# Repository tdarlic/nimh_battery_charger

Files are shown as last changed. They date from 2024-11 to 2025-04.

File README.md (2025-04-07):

# NiMh Battery Charger for 4 AA/AAA batteries

Idea taken from BigClive:
[https://www.reddit.com/r/BigCliveDotCom/comments/tcny85/simple_nimh_battery_charger_with_pcb_files/]

In order to know when the batteries might be charged my plan was to use the timer and a LED. 
I need a 24 hour timer and 555 adds more complications and cannot have 24 hours delays.
Then I tried to get a more modern timer solution but at the end it's much cheaper to use cheap MCU.
That seems wastefull to use MCU only as a timer so I'll ad some fluff to it and maybe connect more batteries to one.

For detecting battery and the timers used ch32v003fun:
[https://github.com/cnlohr/ch32v003fun?tab=readme-ov-file]

Example of the dev board:
[https://oshwlab.com/wagiminator/ch32v003f4p6-development-board]

Development board github:
[https://github.com/wuxx/nanoCH32V003]

To use the WCH-LinkE on Linux, you need to grant access permissions beforehand by executing the following commands:

```shell
echo 'SUBSYSTEM=="usb", ATTR{idVendor}=="1a86", ATTR{idProduct}=="8010", MODE="666"' | sudo tee /etc/udev/rules.d/99-WCH-LinkE.rules
echo 'SUBSYSTEM=="usb", ATTR{idVendor}=="1a86", ATTR{idProduct}=="8012", MODE="666"' | sudo tee -a /etc/udev/rules.d/99-WCH-LinkE.rules
sudo udevadm control --reload-rules

```

To upload firmware and perform debugging, you need to ensure that the development board is disconnected from any power sources. Then, you should make the following connections to the WCH-LinkE:
```
| WCH-LinkE |      | DevBoard |
|-----------|------|----------|
|  SWDIO    | <--> |DIO       |
|    3V3    | ---> |3V3       |
|    GND    | ---> |GND       |

```
## NRST [D7] pin AS GPIO
Must be configured to be GPIO and not NRST pin
```shell
./minichlink -D
```
New make command was added to do this
```shell
make nrstoff
```

## Quick reference
ch32v003f4u6

## Dev board pinout
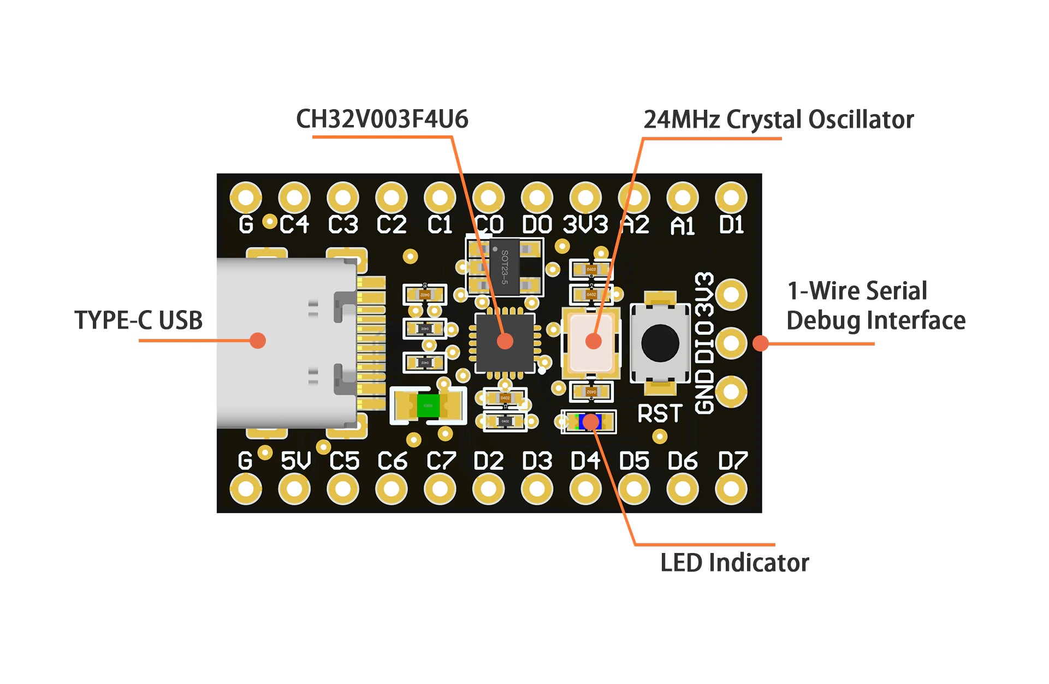
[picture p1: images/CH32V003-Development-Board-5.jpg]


## Dev board schematic 
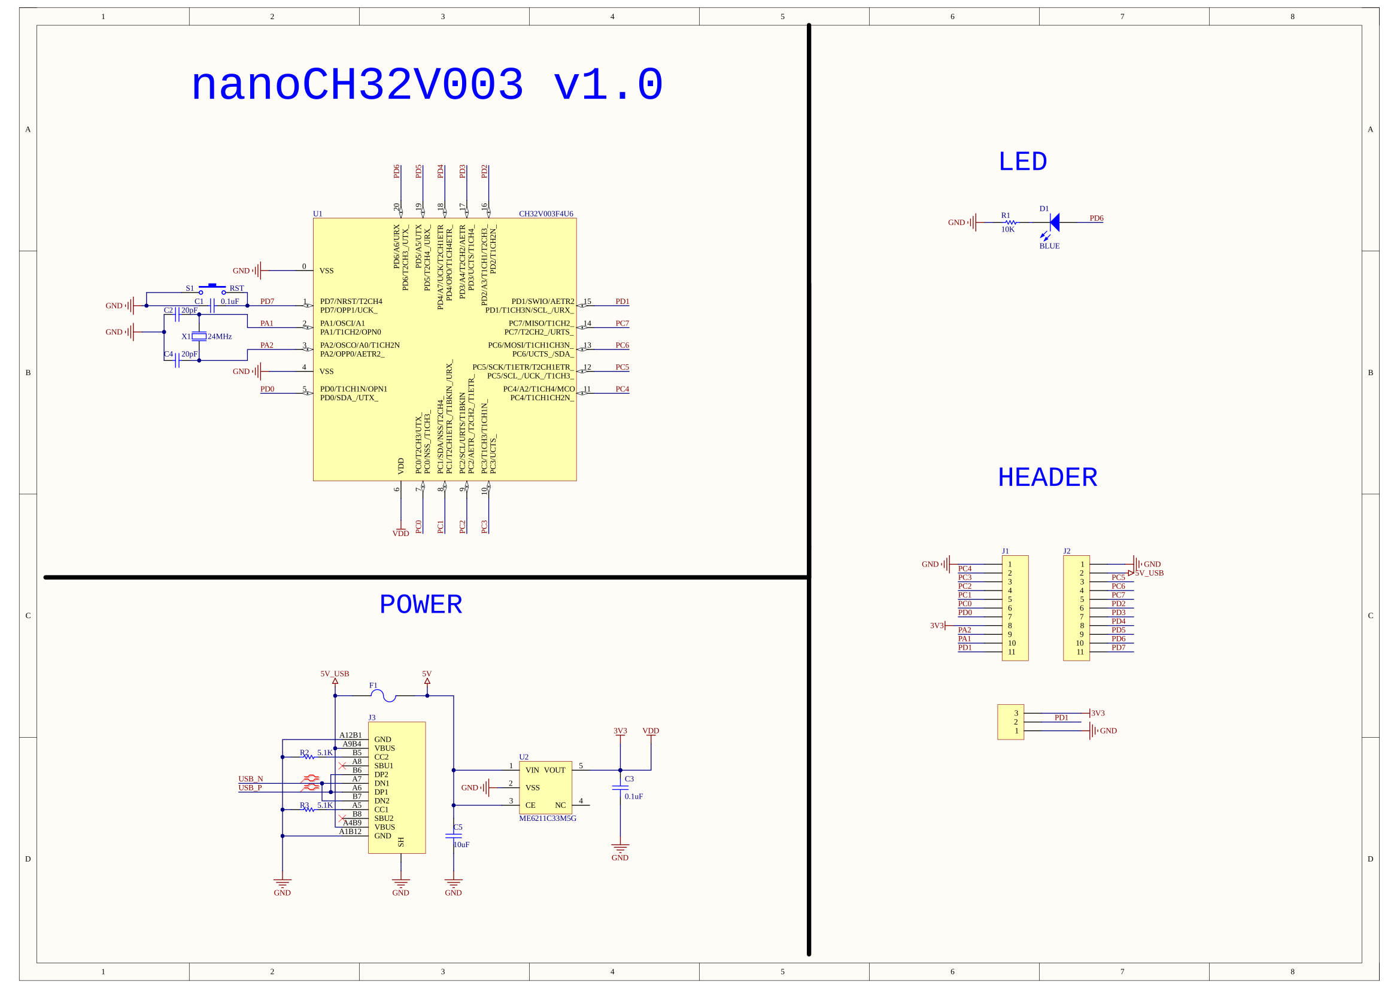
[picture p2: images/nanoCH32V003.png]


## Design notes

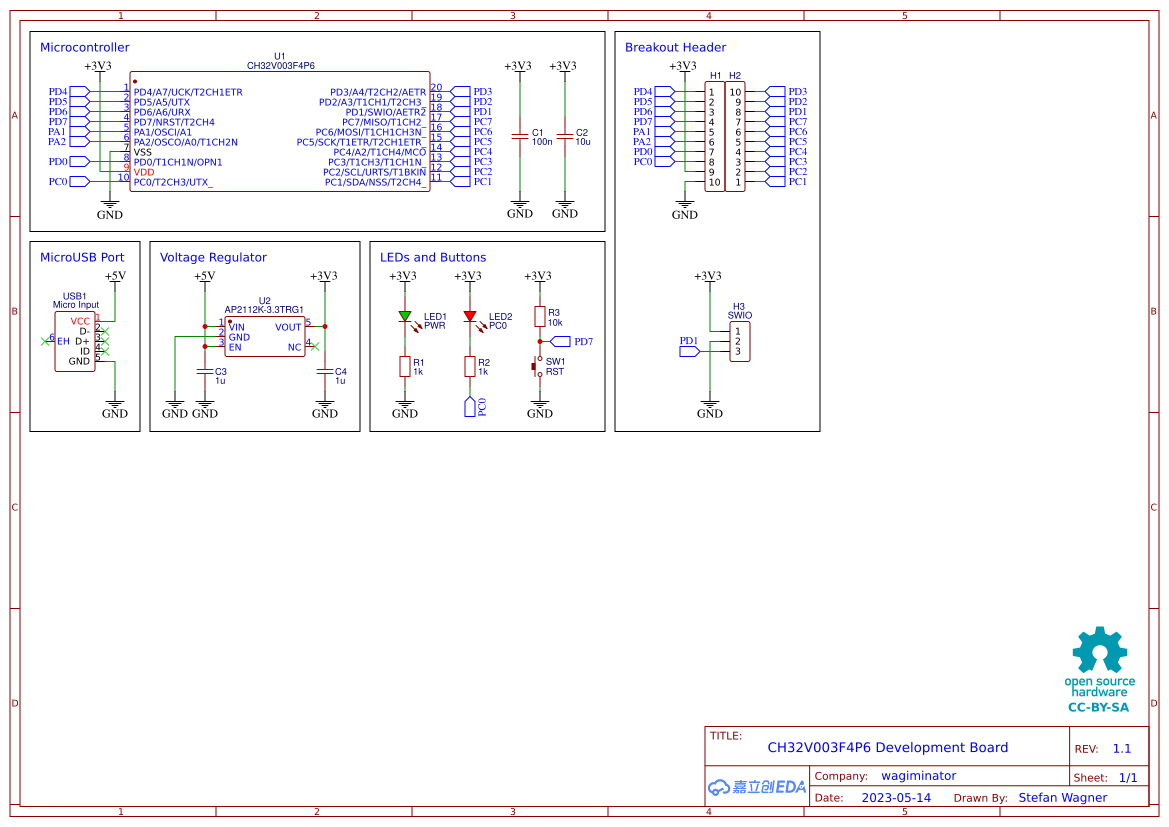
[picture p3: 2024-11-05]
images/36106731c64941528ee92b157d8d4ac0.png

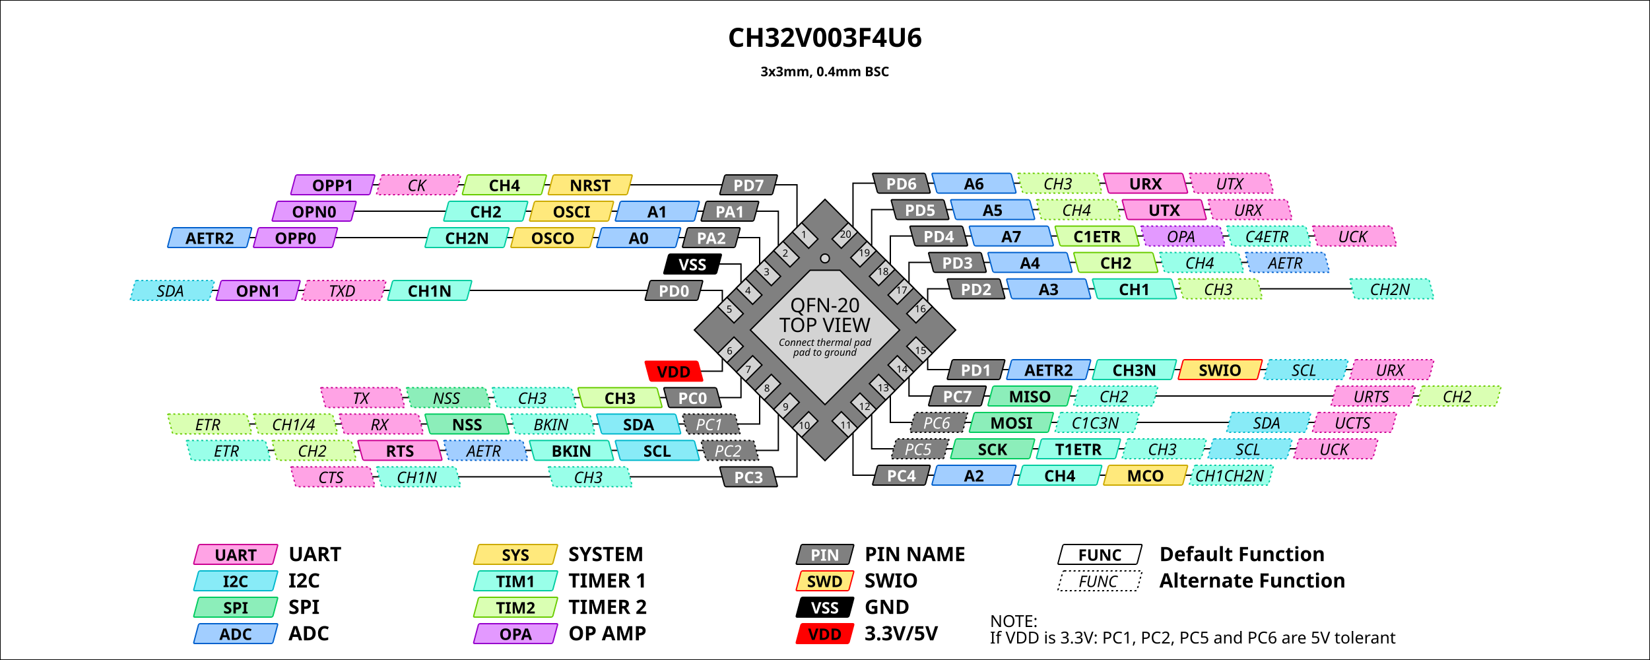
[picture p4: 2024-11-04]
images/ch32v003f4u6.png

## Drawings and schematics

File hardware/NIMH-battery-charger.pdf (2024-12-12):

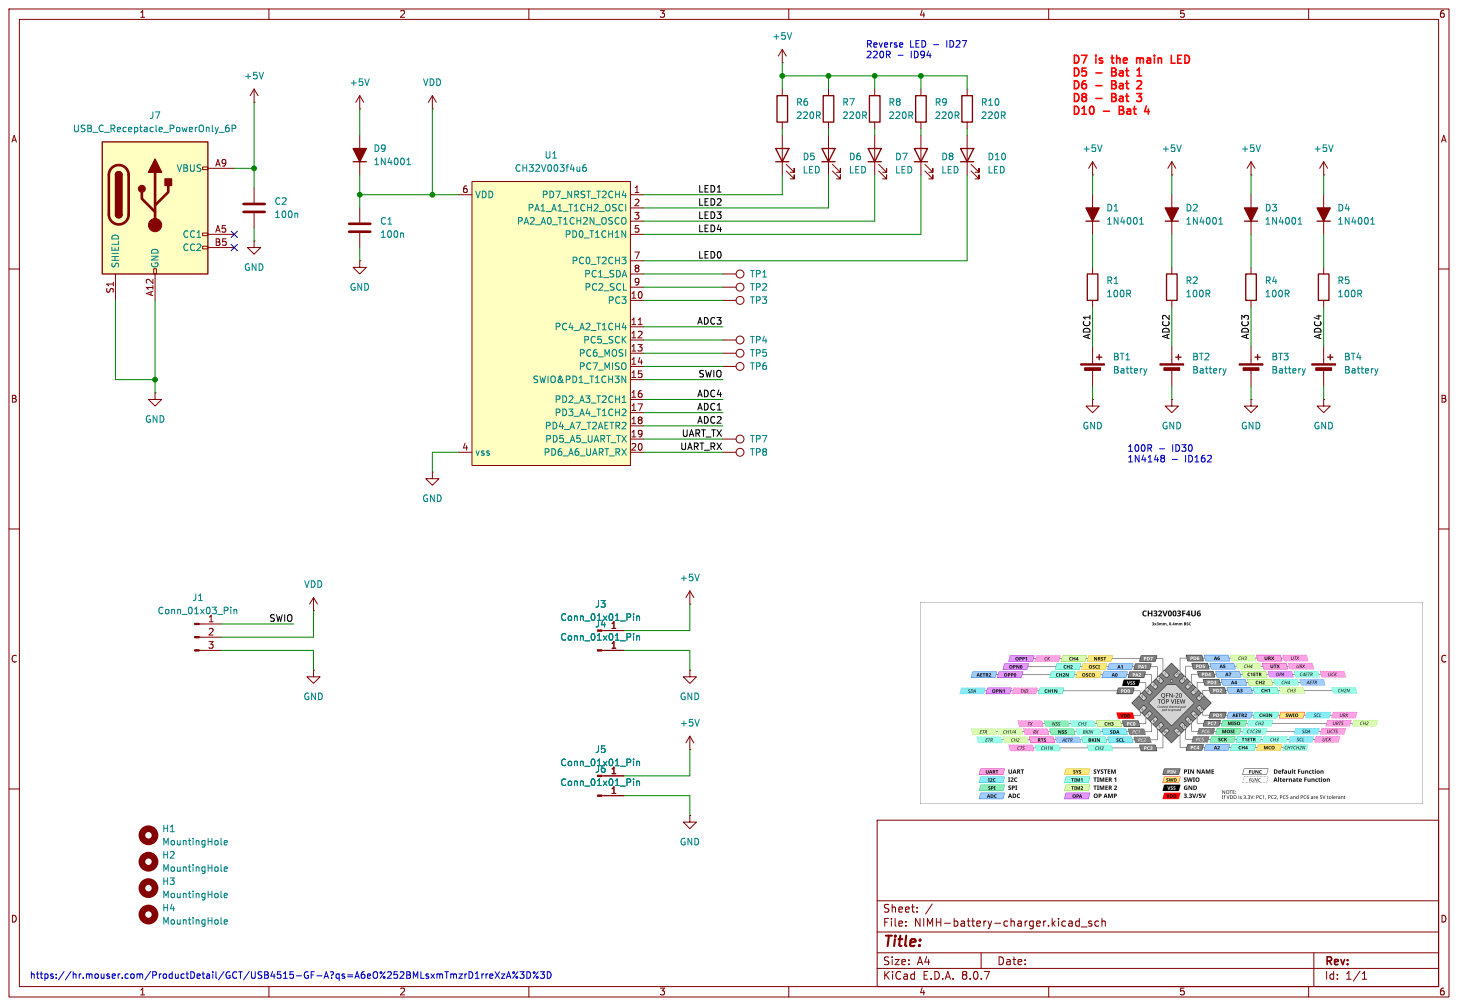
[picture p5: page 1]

D5 - Bat 1 D6 - Bat 2 D8 - Bat 3 D10 - Bat 4

Id: 1/1 Title: File: NIMH-battery-charger.kicad_sch Sheet: / 1

https://hr.mouser.com/ProductDetail/GCT/USB4515-GF-A?qs=A6eO%252BMLsxmTmzrD1rreXzA%3D%3D

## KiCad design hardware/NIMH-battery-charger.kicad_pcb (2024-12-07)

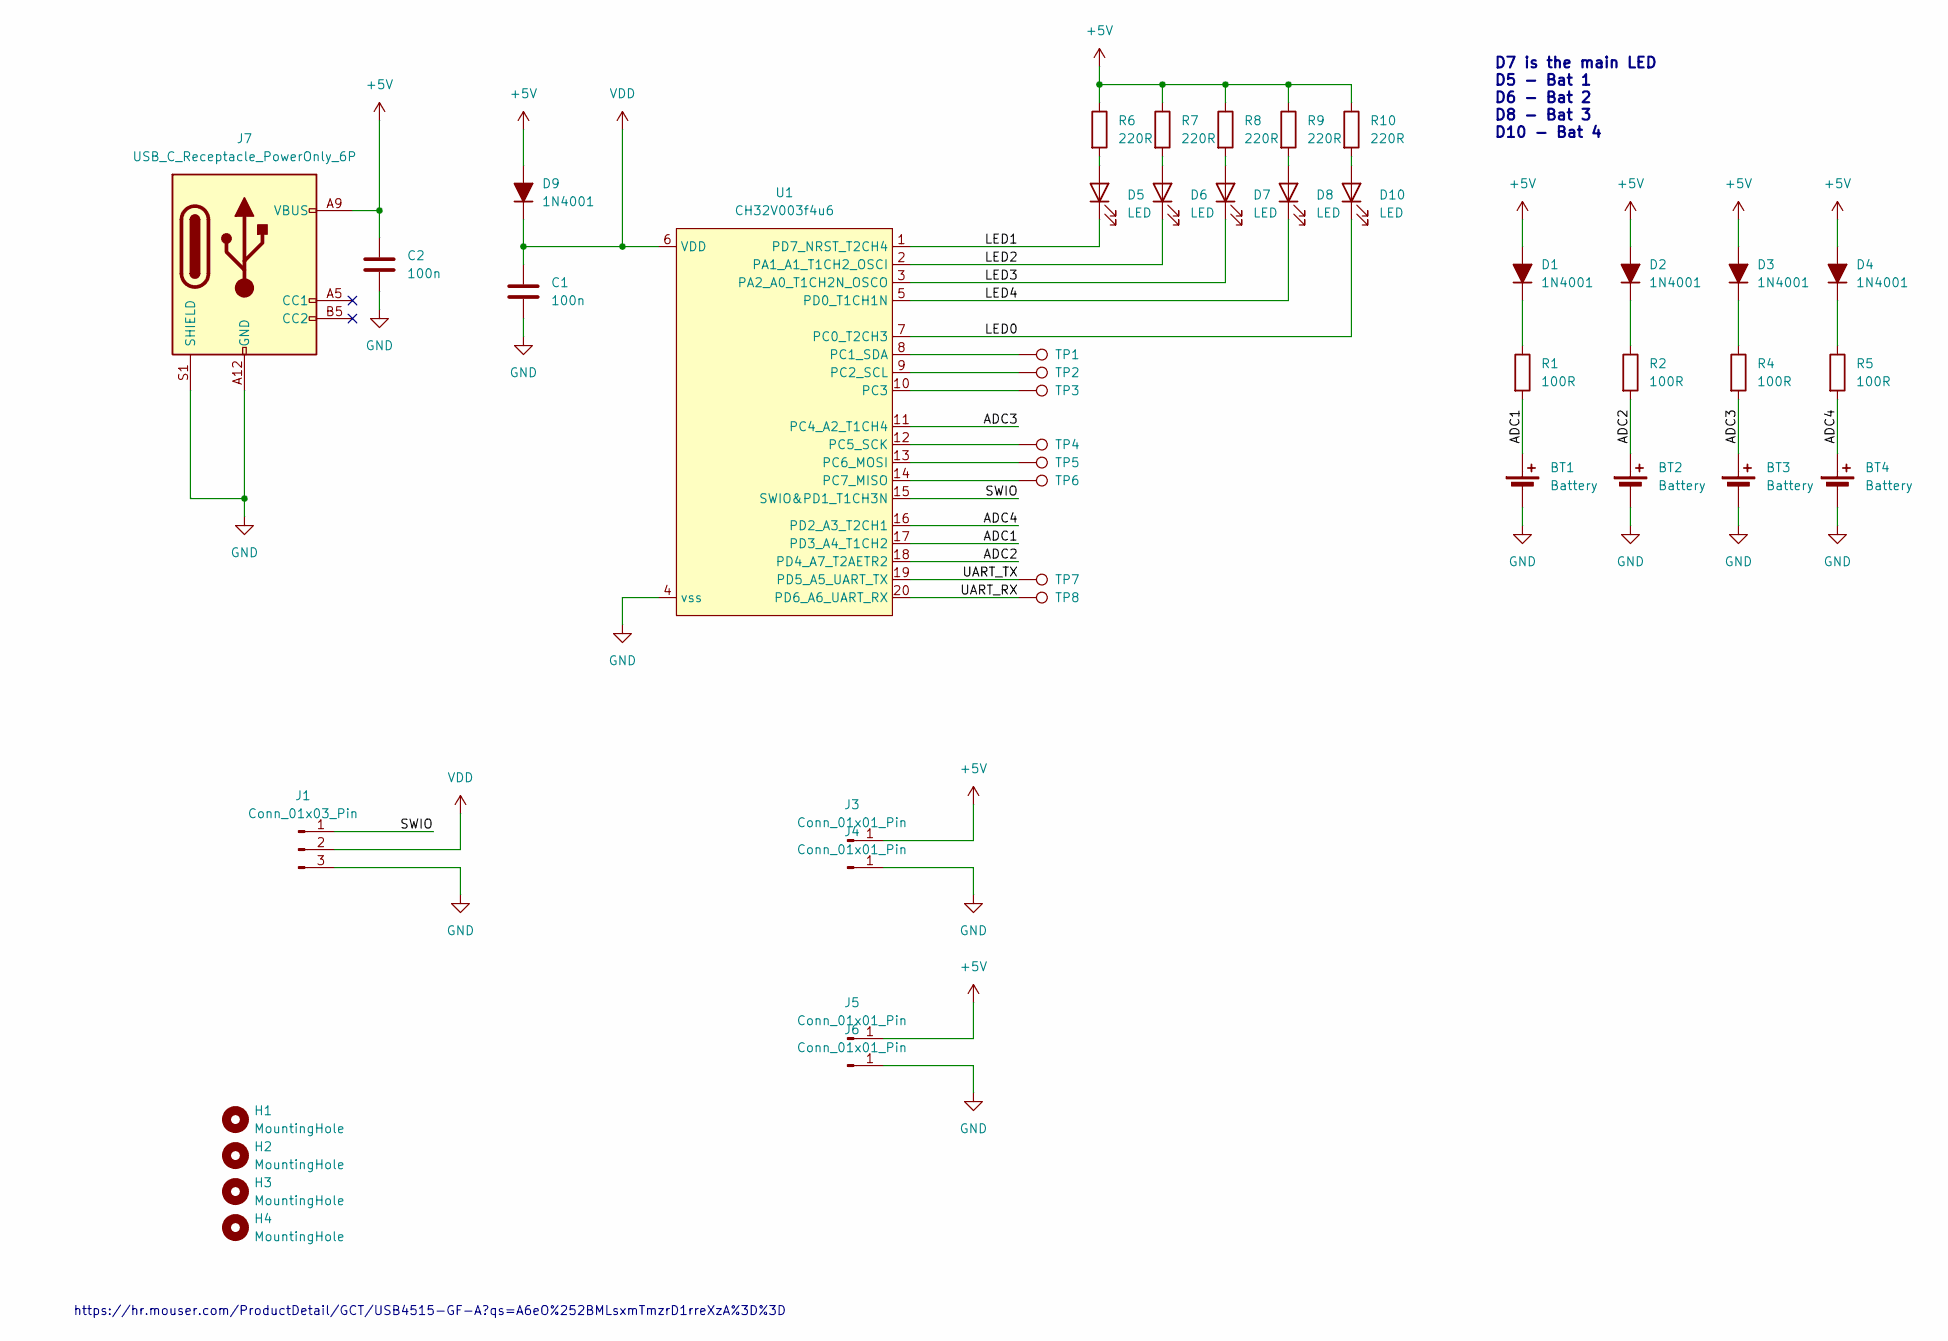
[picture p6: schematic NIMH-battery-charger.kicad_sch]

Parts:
BT1, BT2, BT3, BT4: Battery; UM-3X1-AA
C1, C2: 100n; C_0805_2012Metric_Pad1.18x1.45mm
D1, D2, D3, D4, D9: 1N4001; D_SOD-323_BigPads
D5, D6, D7, D8, D10: LED; LED_1206_3216Metric_ReverseMount_Hole1.8x2.4mm
H1, H2, H3, H4: MountingHole; MountingHole_3.2mm_M3_ISO14580_Pad_TopOnly
J1: Conn_01x03_Pin; Harwin_M20-89003xx_1x03_P2.54mm_Horizontal
J3, J4, J5, J6: Conn_01x01_Pin; PAD
J7: USB_C_Receptacle_PowerOnly_6P; USB4515-GF-A
R1, R2, R4, R5: 100R; R_0805_2012Metric_Pad1.20x1.40mm_HandSolder
R6, R7, R8, R9, R10: 220R; R_0805_2012Metric_Pad1.20x1.40mm_HandSolder
TP1, TP2, TP3, TP4, TP5, TP6, TP7, TP8: TestPoint; TestPoint_Pad_D1.5mm
U1: CH32V003f4u6; QFN-20-1EP_3x3mm_P0.4mm_EP1.65x1.65mm

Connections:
+5V: C2.1, D1.2 (A), D2.2 (A), D3.2 (A), D4.2 (A), D9.2 (A), J3.1, J5.1, J7.A9 (VBUS), J7.B9 (VBUS), R6.1, R7.1, R8.1, R9.1, R10.1
/ADC1: BT1.1 (+), R1.2, U1.17 (PD2_A4_T1CH2)
/ADC2: BT2.1 (+), R2.2, U1.18 (PD4_A7_T2AETR2)
/ADC3: BT3.1 (+), R4.2, U1.11 (PC4_A2_T1CH4)
/ADC4: BT4.1 (+), R5.2, U1.16 (PD2_A3_T2CH1)
/LED0: D10.1 (K), U1.7 (PC0_T2CH3)
/LED1: D5.1 (K), U1.1 (PD7_NRST_T2CH4)
/LED2: D6.1 (K), U1.2 (PA1_A1_T1CH2_OSCI)
/LED3: D7.1 (K), U1.3 (PA2_A0_T1CH2N_OSCO)
/LED4: D8.1 (K), U1.5 (PD0_T1CH1N)
/SWIO: J1.1, U1.15 (SWIO&PD1_T1CH3N)
/UART_RX: TP8.1, U1.20 (PD6_A6_UART_RX)
/UART_TX: TP7.1, U1.19 (PD5_A5_UART_TX)
GND: BT1.2 (-), BT2.2 (-), BT3.2 (-), BT4.2 (-), C1.2, C2.2, J1.3, J4.1, J6.1, J7.A12 (GND), J7.B12 (GND), J7.S1 (SHIELD), U1.4 (vss)
unnamed: D1.1 (K), R1.1
unnamed: D2.1 (K), R2.1
unnamed: D3.1 (K), R4.1
unnamed: D4.1 (K), R5.1
unnamed: D5.2 (A), R6.2
unnamed: D6.2 (A), R7.2
unnamed: D7.2 (A), R8.2
unnamed: D8.2 (A), R9.2
unnamed: D10.2 (A), R10.2
unnamed: TP1.1, U1.8 (PC1_SDA)
unnamed: TP2.1, U1.9 (PC2_SCL)
unnamed: TP3.1, U1.10 (PC3)
unnamed: TP4.1, U1.12 (PC5_SCK)
unnamed: TP5.1, U1.13 (PC6_MOSI)
unnamed: TP6.1, U1.14 (PC7_MISO)
VDD: C1.1, D9.1 (K), J1.2, U1.6 (VDD)

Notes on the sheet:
D7 is the main LED D5 - Bat 1 D6 - Bat 2 D8 - Bat 3 D10 - Bat 4
https://hr.mouser.com/ProductDetail/GCT/USB4515-GF-A?qs=A6eO%252BMLsxmTmzrD1rreXzA%3D%3D

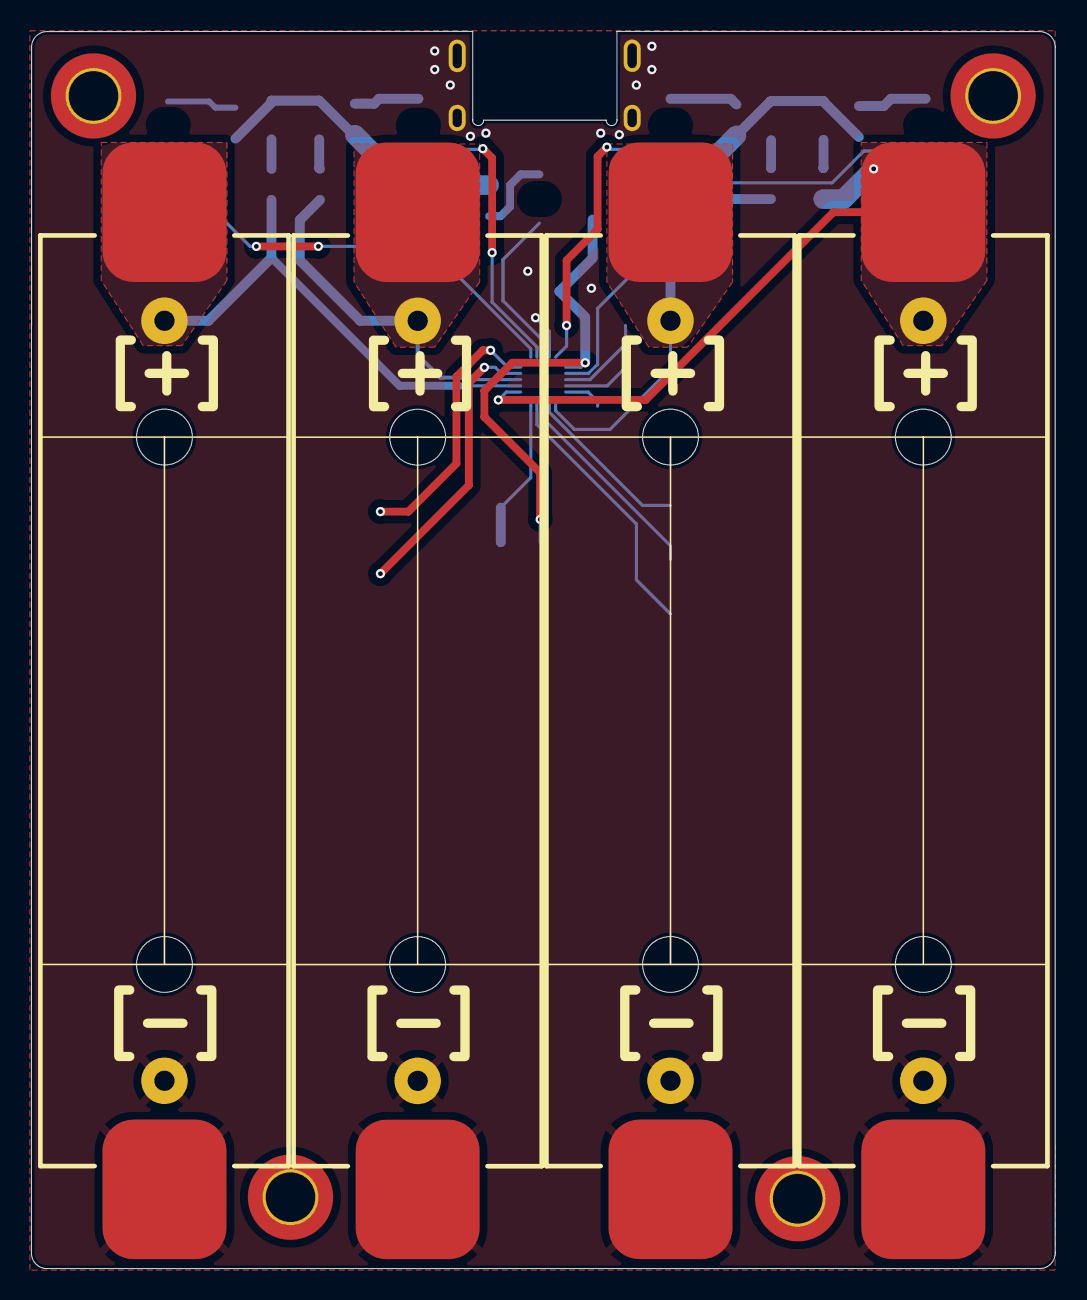
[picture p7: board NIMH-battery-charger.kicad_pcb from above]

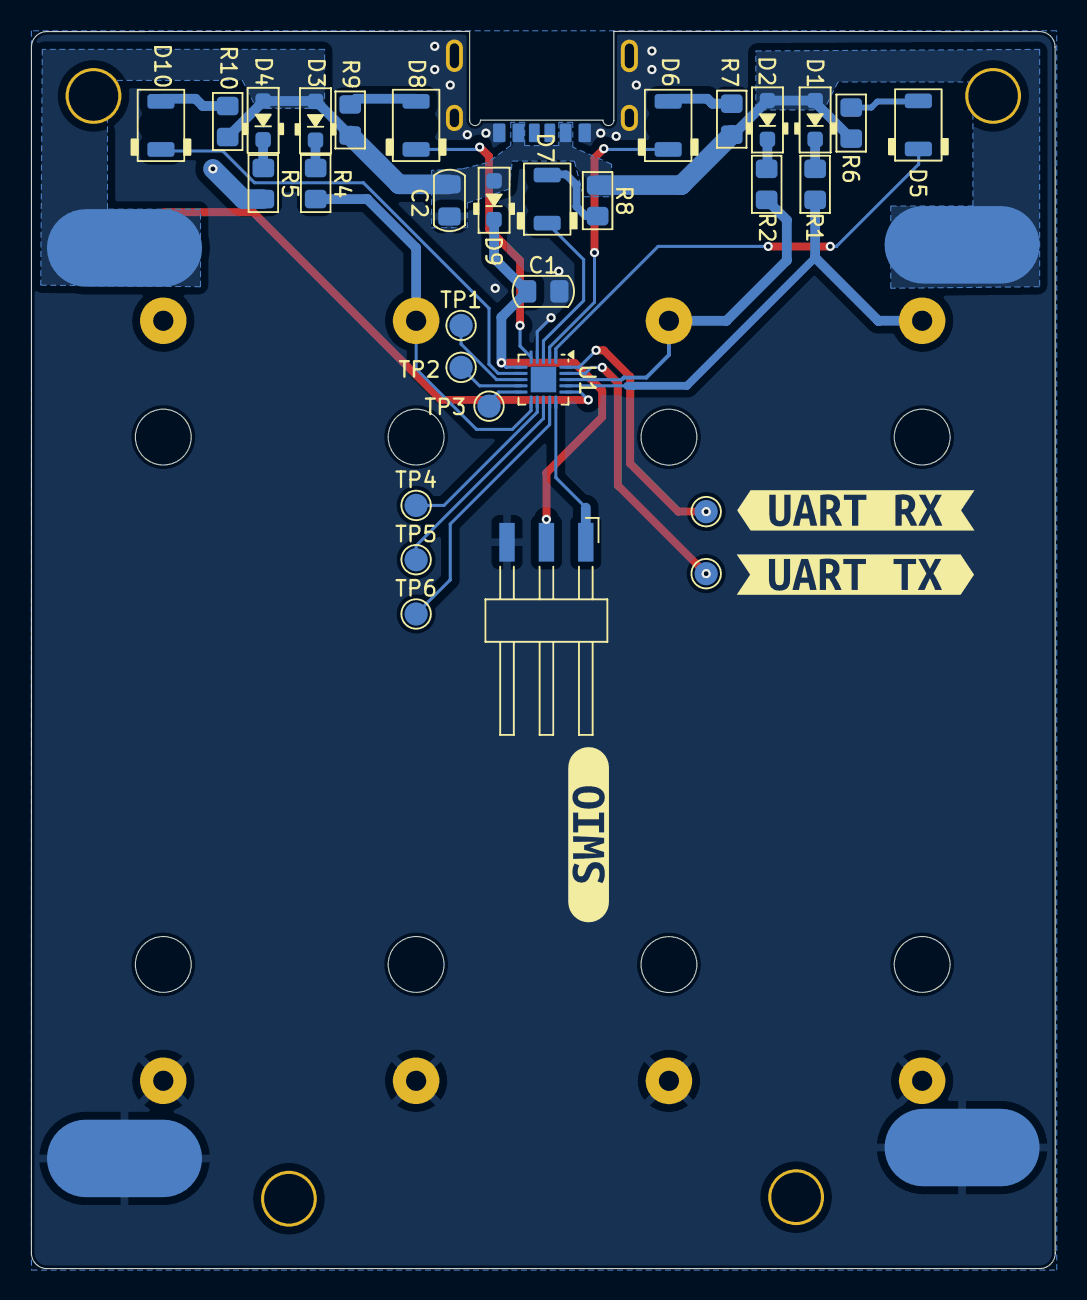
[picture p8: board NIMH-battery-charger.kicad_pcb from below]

Board: 2 copper layers, 66.0 x 79.8 mm, 47 parts (39 on the bottom side), 30 nets.

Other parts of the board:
kibuzzard-672F425B: G***; kibuzzard-672F425B
kibuzzard-672F427A: G***; kibuzzard-672F427A
kibuzzard-672F4251: G***; kibuzzard-672F4251

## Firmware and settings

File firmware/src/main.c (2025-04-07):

#include "ch32v003_GPIO_branchless.h"
#include <stdint.h>
#include <stdio.h>
#include <stdbool.h>

// Number of ticks elapsed per millisecond (48,000 when using 48MHz Clock)
#define SYSTICK_ONE_MILLISECOND ((uint32_t)FUNCONF_SYSTEM_CORE_CLOCK / 1000)
// Number of ticks elapsed per microsecond (48 when using 48MHz Clock)
#define SYSTICK_ONE_MICROSECOND ((uint32_t)FUNCONF_SYSTEM_CORE_CLOCK / 1000000)

// Simple macro functions to give a arduino-like functions to call
// millis() reads the incremented systick variable
// micros() reads the raw SysTick Count, and divides it by the number of 
// ticks per microsecond ( WARN: Wraps every 90 seconds!)
#define millis() (systick_millis)
#define micros() (SysTick->CNT / SYSTICK_ONE_MICROSECOND)

// Incremented in the SysTick IRQ - in this example once per millisecond
volatile uint32_t systick_millis;


// Holds next transition for flasing / PWM leds
uint32_t next = 0;

struct adcval {
		uint16_t adc;
		uint16_t padc;
		uint32_t timer;
};

// Holds the last value of ADC
volatile uint16_t adc1 = 2000, adc2 = 2000, adc3 = 2000, adc4 = 2000;
// Holds the previous value of ADC
volatile uint16_t ch1 = 0, ch2 = 0, ch3 = 0, ch4 = 0;
// vaues of timer
uint32_t tm1 = 0, tm2 = 0, tm3 = 0, tm4 = 0;
// boolean values for PWM
bool cp1 = true, cp2 = true, cp3 = true, cp4 = true;
 
#define DELAYS 200
// ADC treshold - any value below this the system will presume that the battery is charging
#define ADCTR 500

// LED_PERIOD defines PWM duration period
#define LED_PERIOD 500

// After CHARGING_PERIOD in second the LED will not blink indicating charged battery
// By default this is 24 hours
#define CHARGING_PERIOD 24 * 60 * 60

#define BAT1_IN (adc1 < ADCTR) 
#define BAT2_IN (adc2 < ADCTR) 
#define BAT3_IN (adc3 < ADCTR) 
#define BAT4_IN (adc4 < ADCTR) 

#define BAT1_PLUGGED (ch1 > ADCTR)
#define BAT2_PLUGGED (ch2 > ADCTR)
#define BAT3_PLUGGED (ch3 > ADCTR)
#define BAT4_PLUGGED (ch4 > ADCTR)

#define LED_MAIN_ON GPIO_digitalWrite(GPIOv_from_PORT_PIN(GPIO_port_A, 2), low);
#define LED_MAIN_OFF GPIO_digitalWrite(GPIOv_from_PORT_PIN(GPIO_port_A, 2), high)

#define LED1_ON GPIO_digitalWrite(GPIOv_from_PORT_PIN(GPIO_port_D, 7), low)
#define LED1_OFF GPIO_digitalWrite(GPIOv_from_PORT_PIN(GPIO_port_D, 7), high)

#define LED2_ON GPIO_digitalWrite(GPIOv_from_PORT_PIN(GPIO_port_A, 1), low)
#define LED2_OFF GPIO_digitalWrite(GPIOv_from_PORT_PIN(GPIO_port_A, 1), high)

#define LED3_ON GPIO_digitalWrite(GPIOv_from_PORT_PIN(GPIO_port_D, 0), low)
#define LED3_OFF GPIO_digitalWrite(GPIOv_from_PORT_PIN(GPIO_port_D, 0), high)

#define LED4_ON GPIO_digitalWrite(GPIOv_from_PORT_PIN(GPIO_port_C, 0), low)
#define LED4_OFF GPIO_digitalWrite(GPIOv_from_PORT_PIN(GPIO_port_C, 0), high)

/*
 * Initialises the SysTick to trigger an IRQ with auto-reload, using HCLK/1 as
 * its clock source
 */
void systick_init(void)
{
	// Reset any pre-existing configuration
	SysTick->CTLR = 0x0000;

	// Set the compare register to trigger once per millisecond
	SysTick->CMP = SYSTICK_ONE_MILLISECOND - 1;

	// Reset the Count Register, and the global millis counter to 0
	SysTick->CNT = 0x00000000;
	systick_millis = 0x00000000;

	// Set the SysTick Configuration
	// NOTE: By not setting SYSTICK_CTLR_STRE, we maintain compatibility with
	// busywait delay funtions used by ch32v003_fun.
	SysTick->CTLR |= SYSTICK_CTLR_STE   |  // Enable Counter
		SYSTICK_CTLR_STIE  |  // Enable Interrupts
		SYSTICK_CTLR_STCLK ;  // Set Clock Source to HCLK/1

	// Enable the SysTick IRQ
	NVIC_EnableIRQ(SysTicK_IRQn);
}

void pwm(void)
{
	// This holds the length of the PWM cycle in ms
	static bool led_on = true;
	if (systick_millis > next) { 
		if (led_on){
			(BAT1_IN) ? (LED1_ON) : (LED1_OFF);
			(BAT2_IN) ? (LED2_ON) : (LED2_OFF);
			(BAT3_IN) ? (LED3_ON) : (LED3_OFF);
			(BAT4_IN) ? (LED4_ON) : (LED4_OFF);
			led_on = false;
		} else {
			if (BAT1_IN && (cp1)) {LED1_OFF;}
			if (BAT2_IN && (cp2)) {LED2_OFF;}
			if (BAT3_IN && (cp3)) {LED3_OFF;}
			if (BAT4_IN && (cp4)) {LED4_OFF;}
			led_on = true;
		}
		next = systick_millis + LED_PERIOD;
	}
}

/*
 * SysTick ISR - must be lightweight to prevent the CPU from bogging down.
 * Increments Compare Register and systick_millis when triggered (every 1ms)
 * NOTE: the `__attribute__((interrupt))` attribute is very important
 */
void SysTick_Handler(void) __attribute__((interrupt));
void SysTick_Handler(void)
{
	// Increment the Compare Register for the next trigger
	// If more than this number of ticks elapse before the trigger is reset,
	// you may miss your next interrupt trigger
	// (Make sure the IQR is lightweight and CMP value is reasonable)
	SysTick->CMP += SYSTICK_ONE_MILLISECOND;

	// Clear the trigger state for the next IRQ
	SysTick->SR = 0x00000000;

	// Increment the milliseconds count
	systick_millis++;

	// do this every second
	if ((systick_millis % 1000) == 0){
		if (BAT1_IN) {tm1++;}
		if (BAT2_IN) {tm2++;}
		if (BAT3_IN) {tm3++;}
		if (BAT4_IN) {tm4++;}
	}
	pwm();
}


int FLASH_GetBank1Status(void)
{
	int flashstatus = FLASH_COMPLETE;

	if((FLASH->STATR & FLASH_FLAG_BANK1_BSY) == FLASH_FLAG_BSY)
	{
		flashstatus = FLASH_BUSY;
	}
	else
{
		if((FLASH->STATR & FLASH_FLAG_BANK1_WRPRTERR) != 0)
		{
			flashstatus = FLASH_ERROR_WRP;
		}
		else
	{
			flashstatus = FLASH_COMPLETE;
		}
	}
	return flashstatus;
}

int FLASH_WaitForLastOperation(uint32_t Timeout)
{
	int status = FLASH_COMPLETE;

	status = FLASH_GetBank1Status();
	while((status == FLASH_BUSY) && (Timeout != 0x00))
	{
		status = FLASH_GetBank1Status();
		Timeout--;
	}
	if(Timeout == 0x00)
	{
		status = FLASH_TIMEOUT;
	}
	return status;
}

int main()
{
	SystemInit();
	systick_init();
	int status = 0;
	uint16_t OB_STOP = OB_STOP_NoRST;
	uint16_t OB_IWDG = OB_IWDG_SW;
	uint16_t OB_STDBY = OB_STDBY_NoRST;
	uint16_t OB_RST = OB_RST_NoEN;
	uint16_t OB_BOOT = OB_STARTMODE_BOOT;

	FLASH->OBKEYR = FLASH_KEY1;
	FLASH->OBKEYR = FLASH_KEY2;
	status = FLASH_WaitForLastOperation(10000);

	if(status == FLASH_COMPLETE)
	{
		FLASH->CTLR |= CR_OPTPG_Set;
		OB->USER = OB_BOOT | OB_IWDG | (uint16_t)(OB_STOP | (uint16_t)(OB_STDBY | (uint16_t)(OB_RST | (uint16_t)0xc0)));

		status = FLASH_WaitForLastOperation(10000);
		if(status != FLASH_TIMEOUT)
		{
			FLASH->CTLR &= CR_OPTPG_Reset;
		}
	}

	printf( "After Write:%04x\n", OB->USER );

	GPIO_tim1_init();
	NVIC_EnableIRQ(TIM1_UP_IRQn);

	GPIO_port_enable(GPIO_port_C);
	GPIO_port_enable(GPIO_port_D);
	GPIO_port_enable(GPIO_port_A);

	// MAIN LED
	GPIO_pinMode(GPIOv_from_PORT_PIN(GPIO_port_A, 2), GPIO_pinMode_O_pushPull, GPIO_Speed_2MHz);
	// LED1
	GPIO_pinMode(GPIOv_from_PORT_PIN(GPIO_port_D, 7), GPIO_pinMode_O_pushPull, GPIO_Speed_2MHz);
	// LED2
	GPIO_pinMode(GPIOv_from_PORT_PIN(GPIO_port_A, 1), GPIO_pinMode_O_pushPull, GPIO_Speed_2MHz);
	// LED3
	GPIO_pinMode(GPIOv_from_PORT_PIN(GPIO_port_D, 0), GPIO_pinMode_O_pushPull, GPIO_Speed_2MHz);
	// LED4
	GPIO_pinMode(GPIOv_from_PORT_PIN(GPIO_port_C, 0), GPIO_pinMode_O_pushPull, GPIO_Speed_2MHz);
	
	//  switch off all leds
	LED1_OFF;
	LED2_OFF;
	LED3_OFF;
	LED4_OFF;

	// GPIO D3 analog in - PD3 - A4 - ADC1
	GPIO_pinMode(GPIOv_from_PORT_PIN(GPIO_port_D, 3), GPIO_pinMode_I_analog, GPIO_Speed_In);
	// GPIO D4 analog in - PD4 - A7 - ADC2
	GPIO_pinMode(GPIOv_from_PORT_PIN(GPIO_port_D, 4), GPIO_pinMode_I_analog, GPIO_Speed_In);
	// GPIO C4 analog in - PC4 - A2 - ADC3
	GPIO_pinMode(GPIOv_from_PORT_PIN(GPIO_port_C, 4), GPIO_pinMode_I_analog, GPIO_Speed_In);
	// GPIO D2 analog in - PD2 - A3 - ADC4
	GPIO_pinMode(GPIOv_from_PORT_PIN(GPIO_port_D, 2), GPIO_pinMode_I_analog, GPIO_Speed_In);

	GPIO_ADC_set_sampletimes_all(GPIO_ADC_sampletime);
	GPIO_ADCinit();

	// printf("ADC test\n");
	
	while(1)
	{
		LED_MAIN_ON;
		// Read all 4 adc
		adc1 = GPIO_analogRead(GPIO_Ain4_D3);
		adc2 = GPIO_analogRead(GPIO_Ain7_D4);
		adc3 = GPIO_analogRead(GPIO_Ain2_C4);
		adc4 = GPIO_analogRead(GPIO_Ain3_D2);

		// Now reset the timer if battery has just been plugged
		if (BAT1_PLUGGED) {tm1 = 0; cp1 = true;}
		if (BAT2_PLUGGED) {tm2 = 0; cp2 = true;}
		if (BAT3_PLUGGED) {tm3 = 0; cp3 = true;}
		if (BAT4_PLUGGED) {tm4 = 0; cp4 = true;}

		// remeber the old value of ADC
		ch1 = adc1;
		ch2 = adc2;
		ch3 = adc3;
		ch4 = adc4;

		if (tm1 > CHARGING_PERIOD) {cp1 = false;}
		if (tm2 > CHARGING_PERIOD) {cp2 = false;}
		if (tm3 > CHARGING_PERIOD) {cp3 = false;}
		if (tm4 > CHARGING_PERIOD) {cp4 = false;}


		// printf("TIM1_CNT / TIM1_RPTCNT: %d / %d\r\n", TIM1->CNT, TIM1->RPTCR);
		// printf("[%10d] ADC: %d | %d | %d | %d\n", millis(), adc1, adc2, adc3, adc4);
		// printf("[%10d] TIM: %d | %d | %d | %d\n", millis(), tm1, tm2, tm3, tm4);
		// printf("Next:%d\n", next);
		Delay_Ms( DELAYS );
	}
}

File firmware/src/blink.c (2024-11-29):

#include "ch32v003_GPIO_branchless.h"
#include <stdint.h>
#include <stdio.h>

// This is only for devboard
uint16_t adc1, adc2, adc3, adc4 = 0;

#define PIN_LED PD6

#define DELAYS 50
#define MINLED 2
#define MAXLED 30
#define MAXLEDPWM 1600

uint16_t pwmval(){
	static uint8_t cnt = MINLED;
	static int8_t dir = 1;
	uint32_t out = 0;
	
	cnt = cnt + dir;
	out = cnt * cnt * cnt;
	printf("out: %d\n", out);

	if (out > MAXLEDPWM){
		dir = -1;	
	}
	if (cnt < MINLED){
		dir = 1;
	}

	return out;
}

int main()
{
	SystemInit();

	GPIO_port_enable(GPIO_port_C);
	GPIO_port_enable(GPIO_port_D);

	GPIO_pinMode(GPIOv_from_PORT_PIN(GPIO_port_D, 6), GPIO_pinMode_O_pushPull, GPIO_Speed_2MHz);
	
	// GPIO D3 analog in - PD3 - A4 - ADC1
	GPIO_pinMode(GPIOv_from_PORT_PIN(GPIO_port_D, 3), GPIO_pinMode_I_analog, GPIO_Speed_In);
	// GPIO D4 analog in - PD4 - A7 - ADC2
	GPIO_pinMode(GPIOv_from_PORT_PIN(GPIO_port_D, 4), GPIO_pinMode_I_analog, GPIO_Speed_In);
	// GPIO C4 analog in - PC4 - A2 - ADC3
	GPIO_pinMode(GPIOv_from_PORT_PIN(GPIO_port_C, 4), GPIO_pinMode_I_analog, GPIO_Speed_In);
	// GPIO D2 analog in - PD2 - A3 - ADC4
	GPIO_pinMode(GPIOv_from_PORT_PIN(GPIO_port_D, 2), GPIO_pinMode_I_analog, GPIO_Speed_In);

	GPIO_ADC_set_sampletimes_all(GPIO_ADC_sampletime);
	GPIO_ADCinit();

	GPIO_port_pinMode(GPIO_port_D, GPIO_pinMode_O_pushPullMux, GPIO_Speed_10MHz);
	GPIO_tim2_map(GPIO_tim2_output_set_3__C1_C7_D6_D5);
	GPIO_tim2_init();
	GPIO_tim2_enableCH(3);

	printf("ADC test\n");
	while(1)
	{
		GPIO_tim2_analogWrite(3, pwmval());
		// GPIO_digitalWrite(GPIOv_from_PORT_PIN(GPIO_port_D, 6), high);
		// Delay_Ms( DELAYS );
		// GPIO_digitalWrite(GPIOv_from_PORT_PIN(GPIO_port_D, 6), low);
		Delay_Ms( DELAYS );
		// Read all 4 adc
		adc1 = GPIO_analogRead(GPIO_Ain4_D3);
		adc2 = GPIO_analogRead(GPIO_Ain7_D4);
		adc3 = GPIO_analogRead(GPIO_Ain2_C4);
		adc4 = GPIO_analogRead(GPIO_Ain3_D2);
		// printf("ADC: %d | %d | %d | %d\n", adc1, adc2, adc3, adc4);
	}
}

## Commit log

2024-11-04 Add CH32 data, move PCB to hardware folder
    [NIMH-battery-charger.kicad_pcb, NIMH-battery-charger.kicad_sch]
2024-11-05 Add comments for development board
    [NIMH-battery-charger.kicad_pcb, NIMH-battery-charger.kicad_sch]
2024-11-05 Completing schematic and adding comments and images
    [NIMH-battery-charger.kicad_pcb, NIMH-battery-charger.kicad_sch]
2024-11-07 Add USB_C receptacle
    Add documents
    Resizing the board
    [NIMH-battery-charger.kicad_pcb, NIMH-battery-charger.kicad_sch]
2024-11-07 Add leds
    [NIMH-battery-charger.kicad_pcb, NIMH-battery-charger.kicad_sch]
2024-11-07 Moving Leds
    [NIMH-battery-charger.kicad_pcb]
2024-11-07 Placed all components on board
    Finalizing PCB
    Add all components and place them for routing
    [NIMH-battery-charger.kicad_pcb, NIMH-battery-charger.kicad_sch]
2024-11-07 Adding soild GND connection to some pins of USB connector
    [NIMH-battery-charger.kicad_pcb, NIMH-battery-charger.kicad_sch]
2024-11-07 Add dimensions and created first gerbers
    [NIMH-battery-charger-B_Cu.gbr, NIMH-battery-charger-B_Mask.gbr, NIMH-battery-charger-B_Paste.gbr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]
2024-11-08 Started routing board
    [NIMH-battery-charger.kicad_pcb]
2024-11-09 Completed routing board
    Created gergers for JLCPCB
    Added mounting holes
    [NIMH-battery-charger-B_Cu.gbr, NIMH-battery-charger-B_Mask.gbr, NIMH-battery-charger-B_Paste.gbr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]
2024-11-29 Got the ADC working sucessfully
    Add better schematic for nanoCH32V003
    [NIMH-battery-charger.kicad_sch]
2024-11-29 Add nicer PWM value calculation function
2024-11-30 Rename source file made for the nanoCH32V003 board
2024-12-01 Corrected the clock with FUNCONF_SYSTICK_USE_HCLK
    [nanoCH32V003.c]
2024-12-01 Added comments on LED placement on PCB
    Changed nanoCH32V003 code to print ADC immediately after start
    [NIMH-battery-charger.kicad_sch]
2024-12-07 Add larger holes for the battery holder
    [NIMH-battery-charger.kicad_pcb]
2024-12-12 Add separte folders for main and devboard code
    Add comments to hardware
    [NIMH-battery-charger.kicad_sch]
2024-12-14 Fix GPIO status for on off and fix pin1 D7 set as GPIO not nRST
    [main.c]
2024-12-17 Add working charging indicator for 24 hours
2024-12-17 Remove debug print lines
2024-12-17 Add configuration to stop debug printf
2024-12-31 Adding comment to change the resistors
    [NIMH-battery-charger.kicad_sch]
2025-01-02 Add comments on measured charging current
    [NIMH-battery-charger.kicad_sch]
2025-04-07 Configure NRST as GPIO
    Added comment to configure NRST [D7] pin as GPIO
    Each new chip needs to be configured with this otherwise LED1 will not
    work
    Removed some unnecessary variables
